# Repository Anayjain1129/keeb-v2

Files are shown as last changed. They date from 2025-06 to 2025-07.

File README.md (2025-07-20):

A badge of a Cerberus and a raccoon laughing together, with the text "HIGHWAY" and "HACK CLUB" beside them.

# Keeb
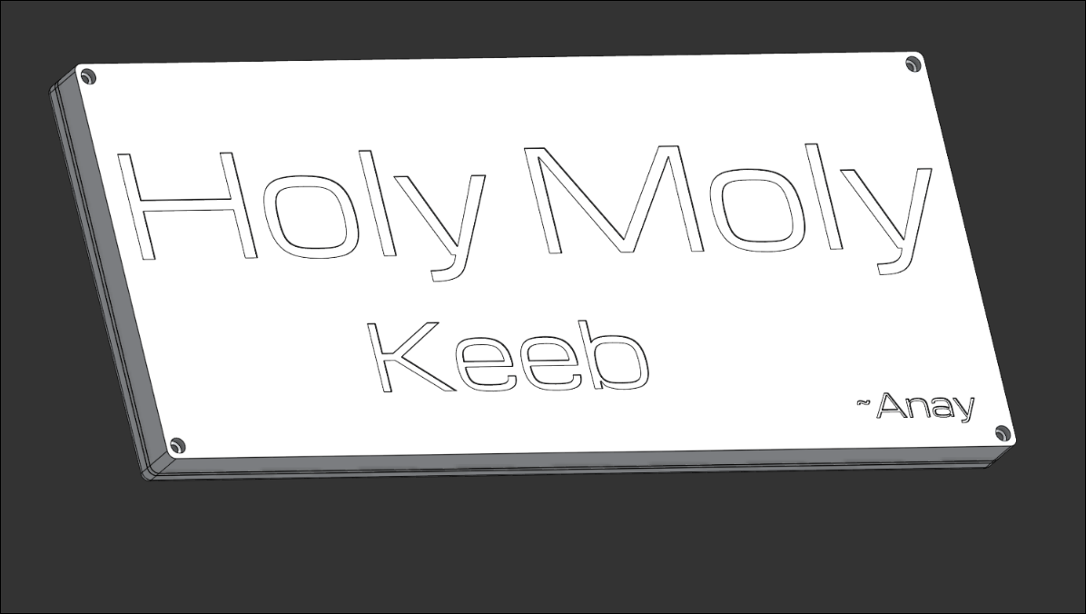
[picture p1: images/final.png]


### Why did I make it?
I made it cause I have a freaking 60% keeb and I really need function keys also It has 2 RE which i can use for like brightness or volume stuff.

### What was the hardest part about this ?
It think everthing was cause it's like I love to learn new things so yea I love to make and learn new thing.

Features:

- 2x EC11 Rotary Encoder - For Volume, Brightness etc
- 74x keys
- Raspberry Pi Pico
- Customised layout
- QMK firmware
- Highway branded PCB and case

### Schematic
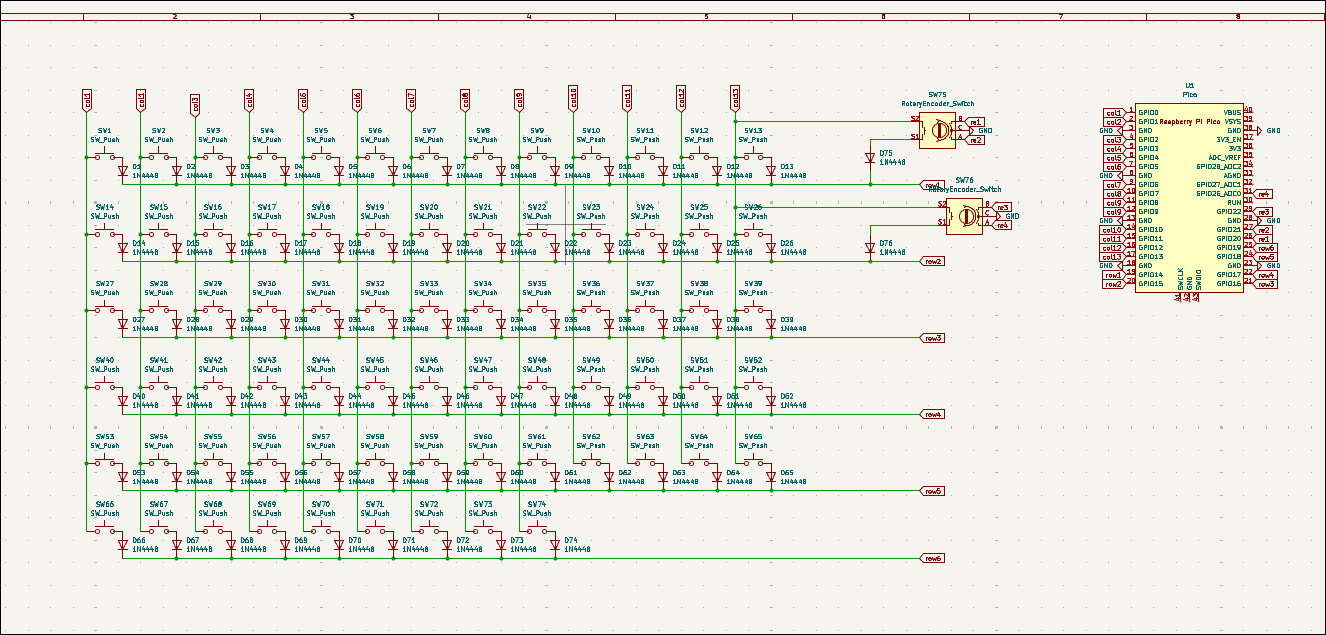
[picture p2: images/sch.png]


### PCB 
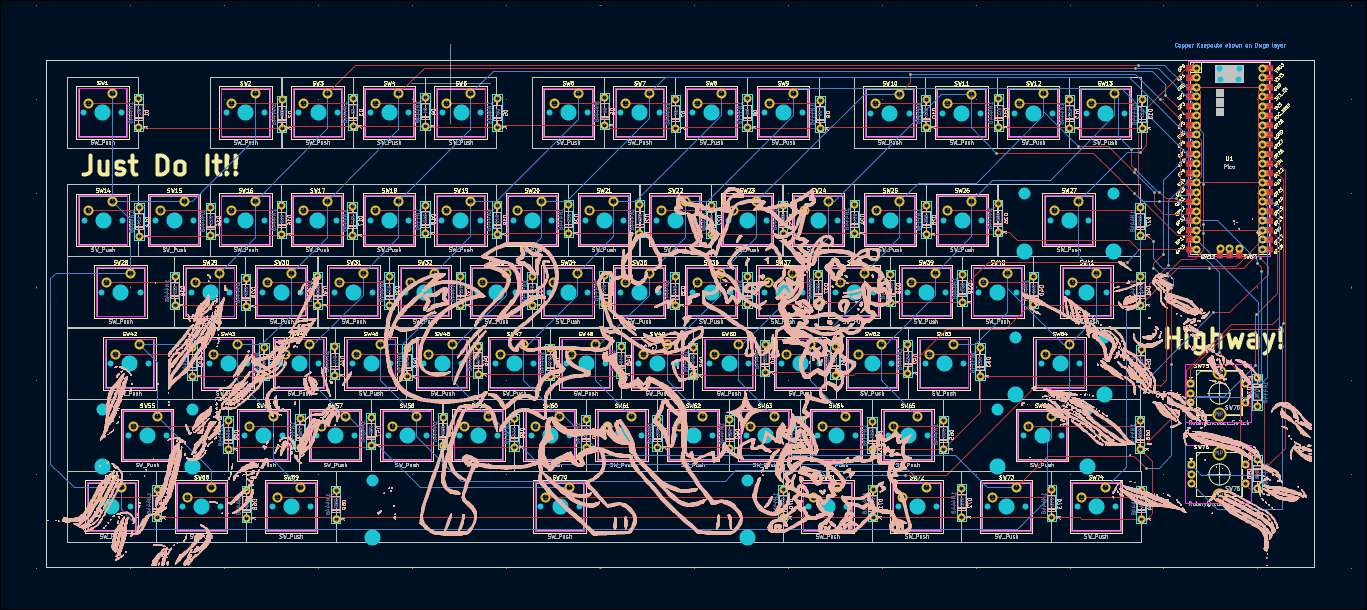
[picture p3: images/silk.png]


### Case
- Bottom
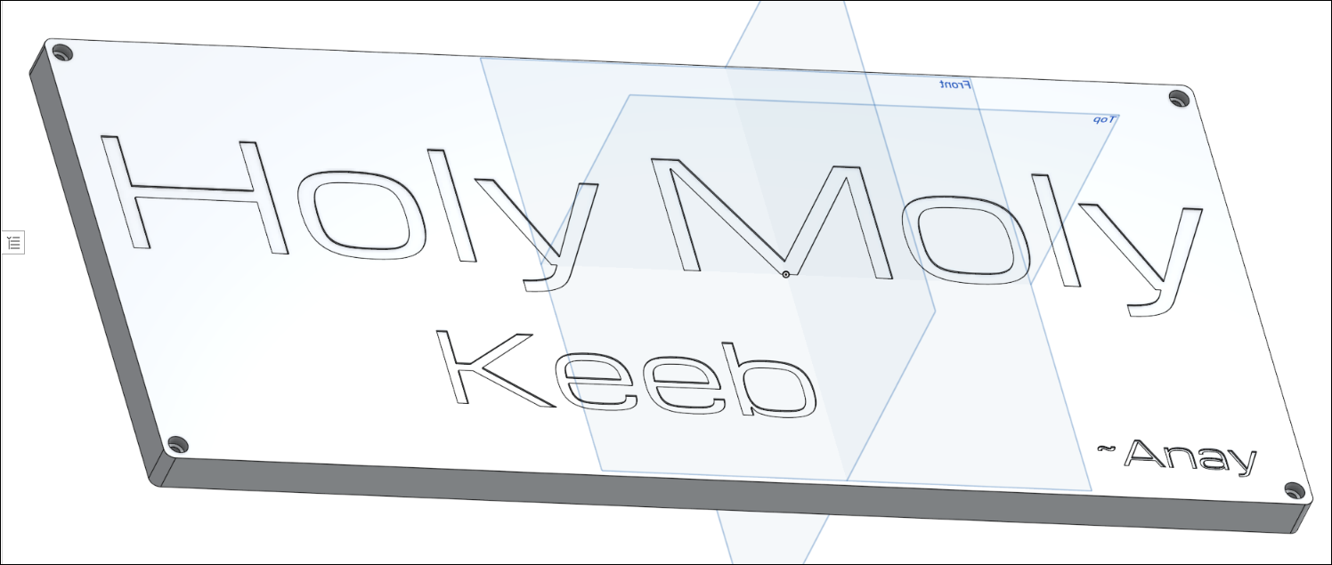
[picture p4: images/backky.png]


- Middle plate
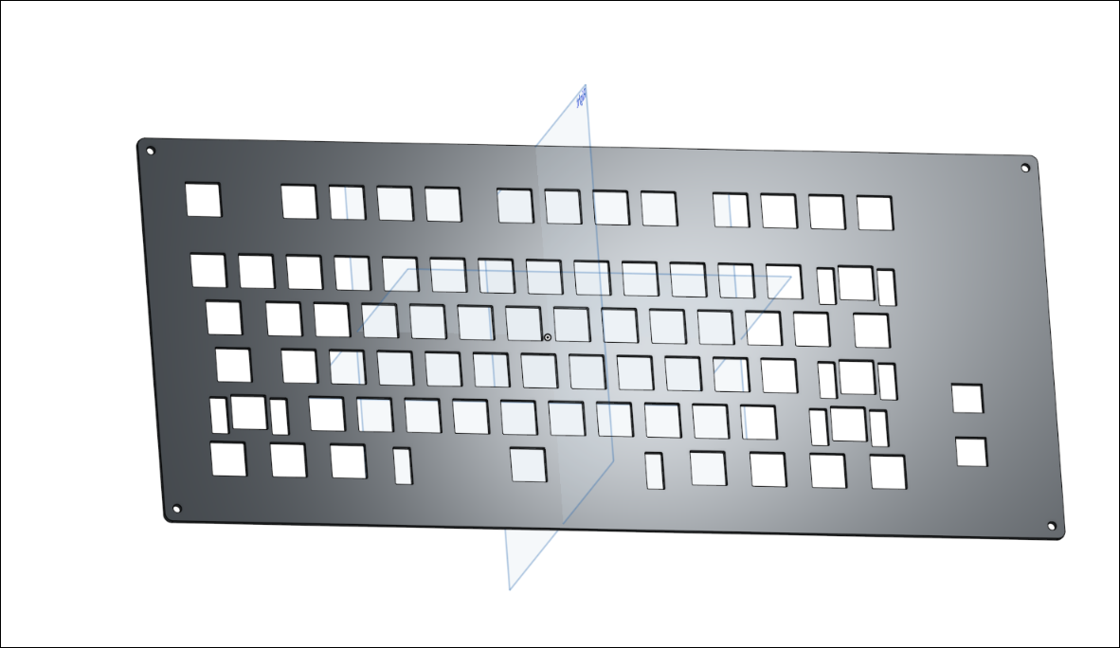
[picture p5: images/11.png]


- Top
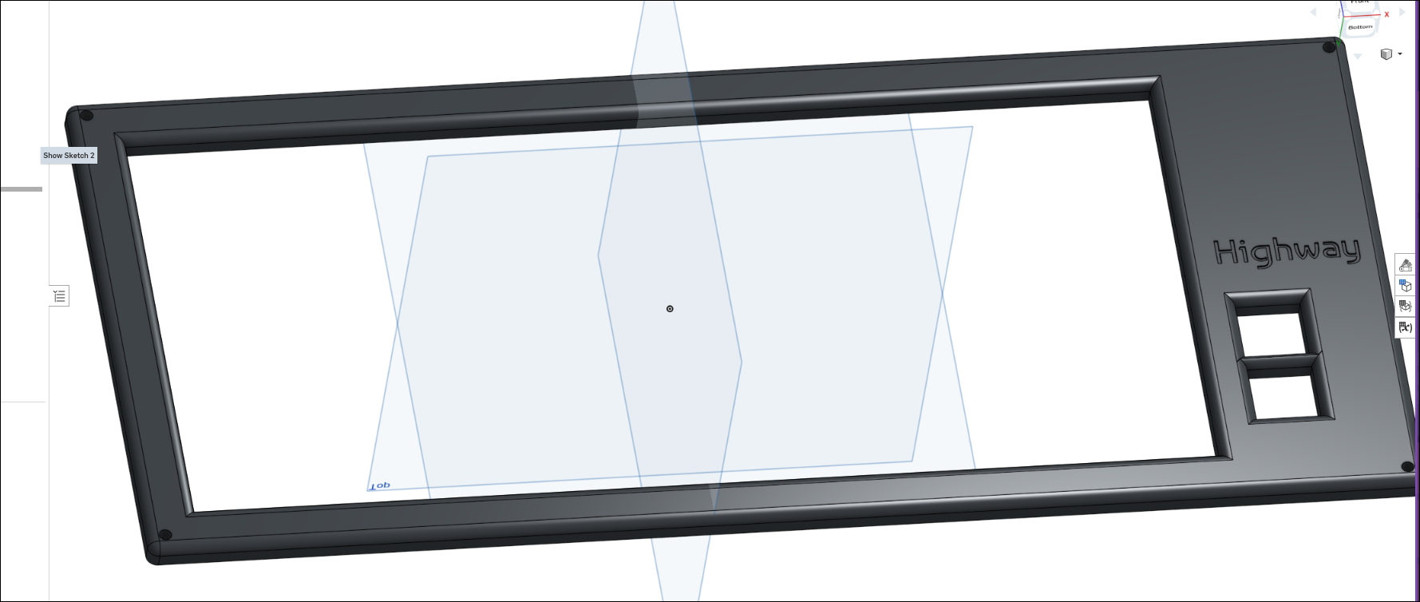
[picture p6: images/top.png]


### 3D view of all parts together 
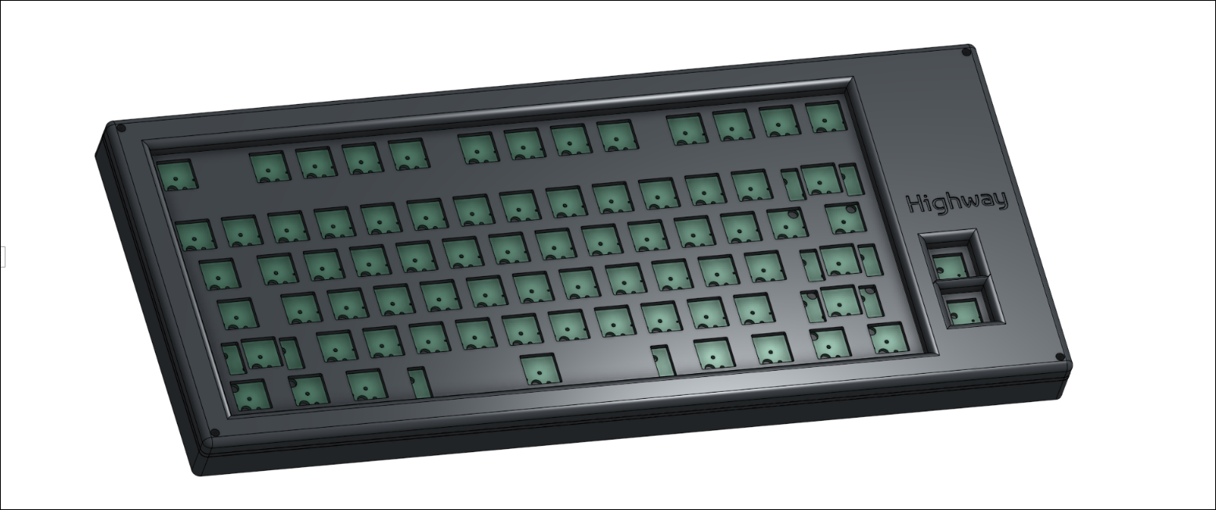
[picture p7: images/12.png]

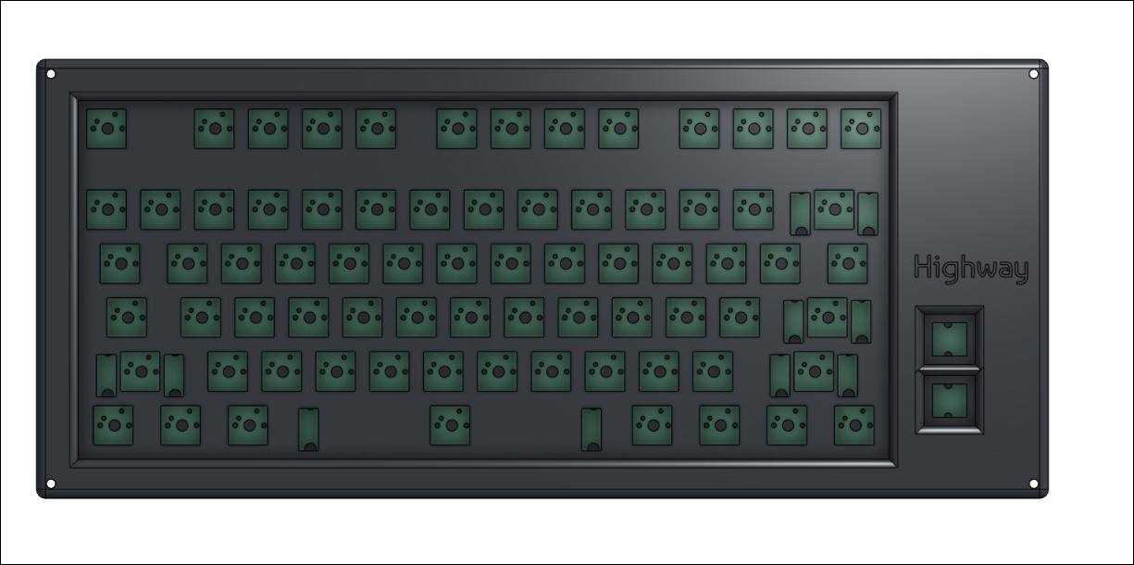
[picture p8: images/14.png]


### Stickers & Handcolor
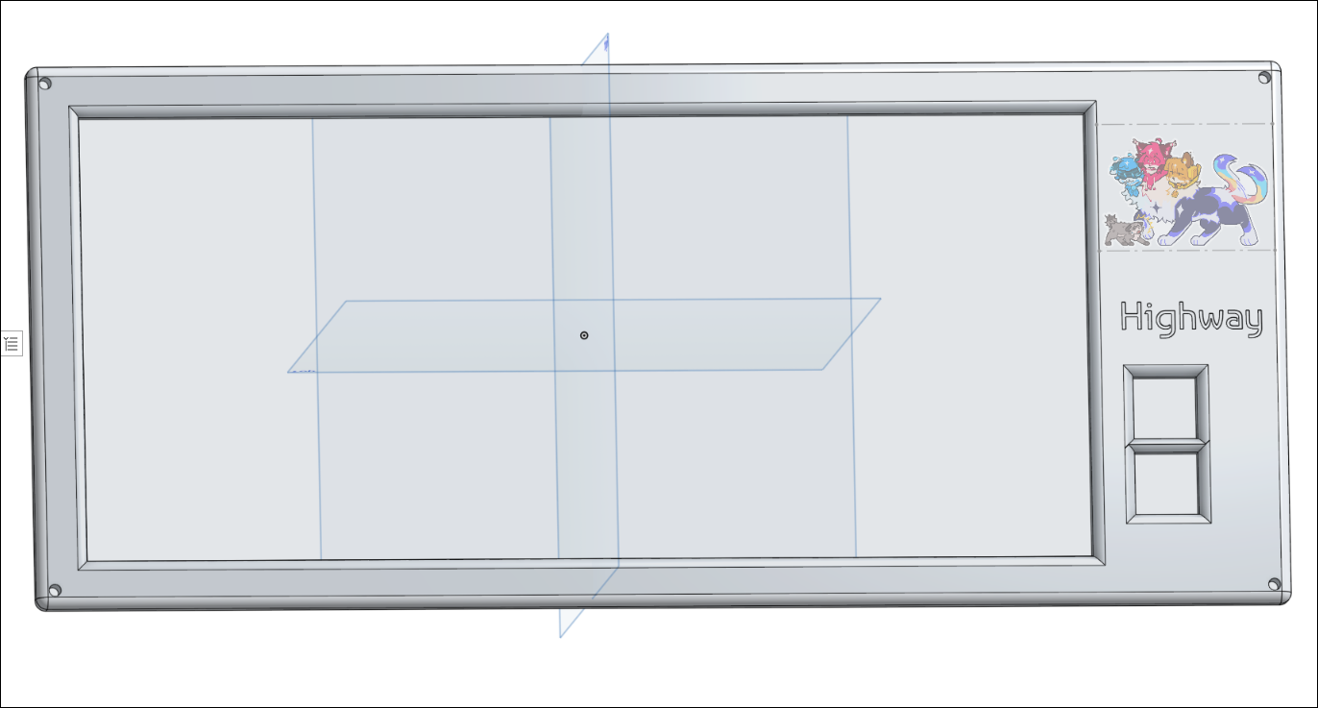
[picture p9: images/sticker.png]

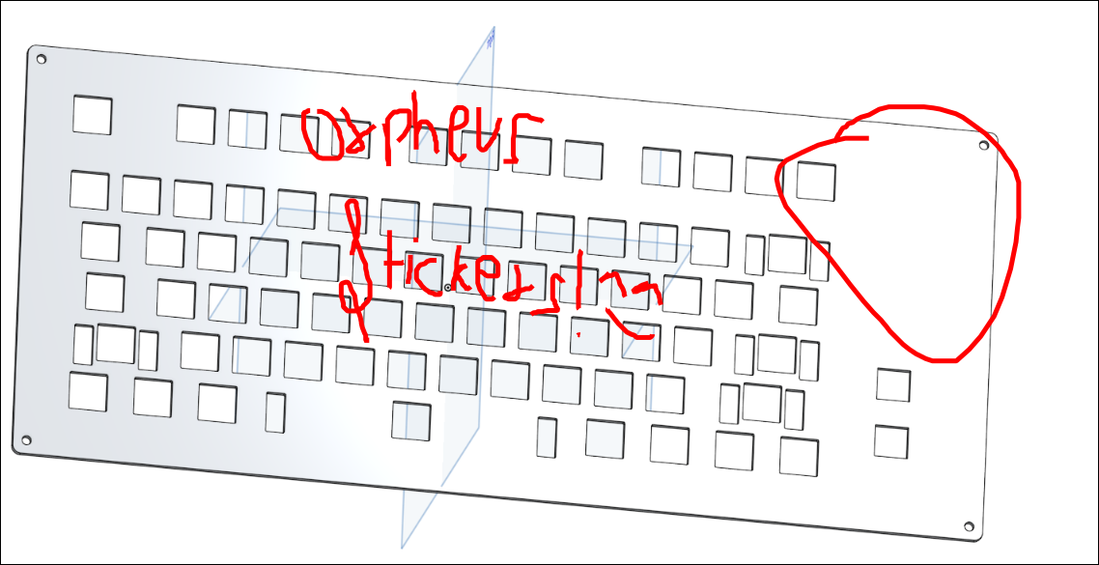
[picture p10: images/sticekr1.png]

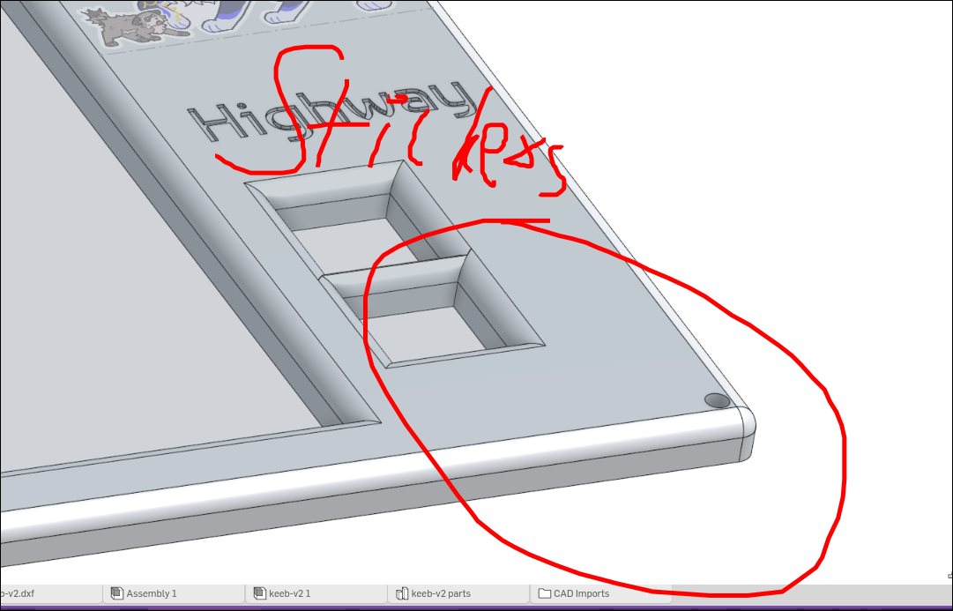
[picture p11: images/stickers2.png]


-Paint
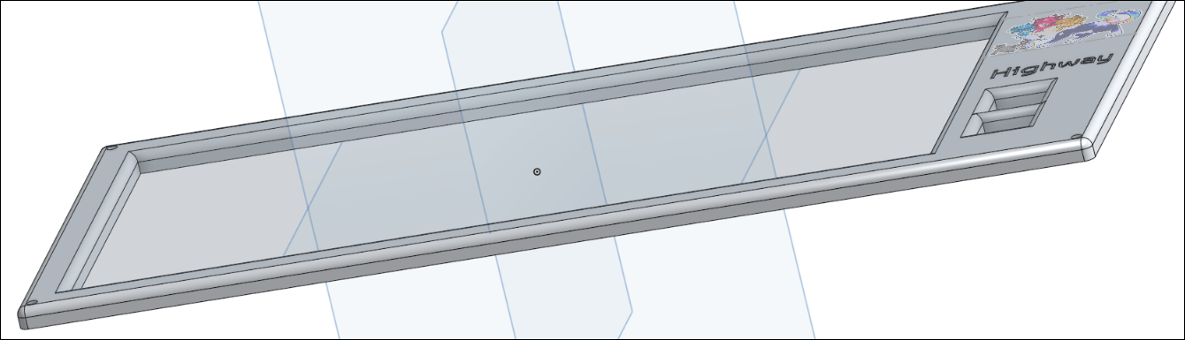
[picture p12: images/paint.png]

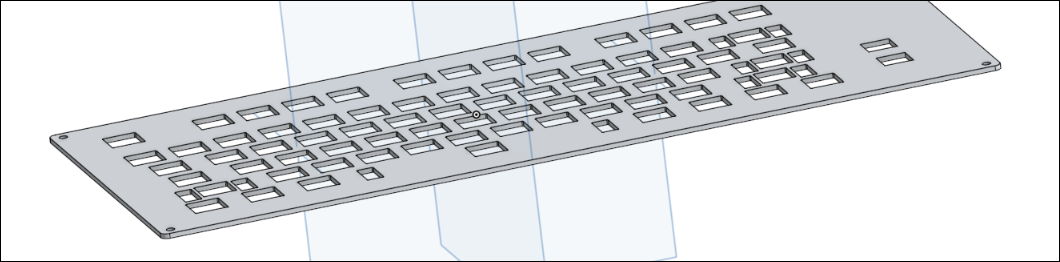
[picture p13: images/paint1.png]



Also at the back part which i have craved some part it is because I'm gonna hand paint it to make it more attractive, I wasn't about to use Blender because I'm cyurrently on Arch and im facing issues. I hope my keeb gets approved now!
I got my sister who is artist so yea sh'e currntly out of station rn but she so many ideas, And like I got so many hackclub stickers so I will use them too.


I have more But I dont have phone rn so i can not take pictures 


I have more But I dont have phone rn so i can not take pictures 

## BOM

| Name | Qty | Final Price - INR (USD) | Link |
| --- | --- | --- | --- |
| Gateron EF Grayish | 80  | 1560 ($18.19) | [here](https://neomacro.in/products/gateron-ef-grayish) |
| Durock Smokey Screw-In Stabilizers V2 (4+1 w/ 6.25u spacebar) | 1 | 1590 ($18.58) | [here](https://stackskb.com/store/durock-smokey-screw-in-stabilizers-v2/) |
| Cherry Profile PBT Keycaps | 1 | 1300 ($15.15) | [here](https://stackskb.com/store/veekos-gradient-keycaps-cherry-profile-135-keys) |
| Diode 1N4148 Through - Hole | 100 | 100 ($1.17) | [here](https://amzn.in/d/j3eLvoh) |
| EC11 Rotary Encoder | 2 | 178 ($2.08) | [here](https://amzn.in/d/hVRxzij) |
| M3 x 20mm Bolt | 15  | 149 ($1.73) | [here](https://amzn.in/d/8GRQWAB) |
| M3 Nuts | 8 | 100 ($1.16) | [here](https://amzn.in/d/7UQtsm8) |
| M3 x 5mm Heatset Insert | 25  | 179 ($2.09) | [here](https://amzn.in/d/ixybuAc) |
| PCB - (Black Color) | 5 | 6683 ($77.78) ||
| Raspberry Pi Pico | 1 | 449 ($5.19) | [here](http://amazon.in/Raspberry-Pi-Headers-Soldered-Micro/dp/B08WPNM7JB/ref=sr_1_2?sr=8-2) |
| Top Case | 1 | Print Legion |
| Bottom Case | 1 | Print Legion |
| Middle Plate | 1 | Print Legion |

## Total Pricing
The total price comes out to be 11,956.35 INR ($139.31) I'm not including the cost of case cause I will get it printed from Print Legion.

The pricing might slightly vary due to flash sales, and dollar market trends.

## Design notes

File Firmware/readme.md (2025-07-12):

# keeb

keeb

*A short description of the keyboard/project*

* Keyboard Maintainer: [anay](https://github.com/anay)
* Hardware Supported: *The PCBs, controllers supported*
* Hardware Availability: *Links to where you can find this hardware*

Make example for this keyboard (after setting up your build environment):

    make keeb:default

Flashing example for this keyboard:

    make keeb:default:flash

See the [build environment setup](https://docs.qmk.fm/#/getting_started_build_tools) and the [make instructions](https://docs.qmk.fm/#/getting_started_make_guide) for more information. Brand new to QMK? Start with our [Complete Newbs Guide](https://docs.qmk.fm/#/newbs).

## Bootloader

Enter the bootloader in 3 ways:

* **Bootmagic reset**: Hold down the key at (0,0) in the matrix (usually the top left key or Escape) and plug in the keyboard
* **Physical reset button**: Briefly press the button on the back of the PCB - some may have pads you must short instead
* **Keycode in layout**: Press the key mapped to `QK_BOOT` if it is available

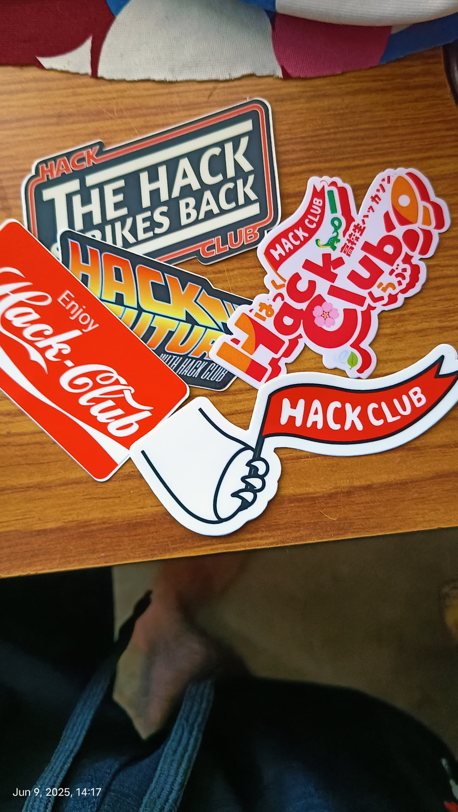
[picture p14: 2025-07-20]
images/col.jpeg

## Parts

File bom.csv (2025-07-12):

Name | Qty | Final Price- INR (USD) | Link
Gateron EF Grayish | 80 | 1560 ($18.19) | https://neomacro.in/products/gateron-ef-grayish
Durock Smokey Screw-In Stabilizers V2 | 1 | 1595 ($18.58) | https://stackskb.com/store/durock-smokey-screw-in-stabilizers-v2/
Cherry Profile PBT Keycaps | 1 | 1300 ($15.15) | https://stackskb.com/store/veekos-gradient-keycaps-cherry-profile-135-keys
Diode 1N4148 Through – Hole | 100 | 100 ($1.17) | https://amzn.in/d/j3eLvoh
EC11 Rotary Encoder | 2 | 178 ($2.08) | https://amzn.in/d/hVRxzij
M3 x 20mm Bolt | 15 | 149 ($1.73) | https://amzn.in/d/8GRQWAB
M3 Nuts | 8 | 100 ($1.16) | https://amzn.in/d/7UQtsm8
M3 x 5mm Heatset Insert | 25 | 179 ($2.09) | https://amzn.in/d/ixybuAc
Raspberry Pi Pico | 1 | 449 ($5.19) | https://www.amazon.in/Raspberry-Pi-Headers-Soldered-Micro/dp/B08WPNM7JB/ref=sr_1_2?sr=8-2
PCB | 5 | 6683 ($77.78)
Top Case | 1 | Print Legion
Bottom Case | 1 | Print Legion
Middle Plate | 1 | Print Legion

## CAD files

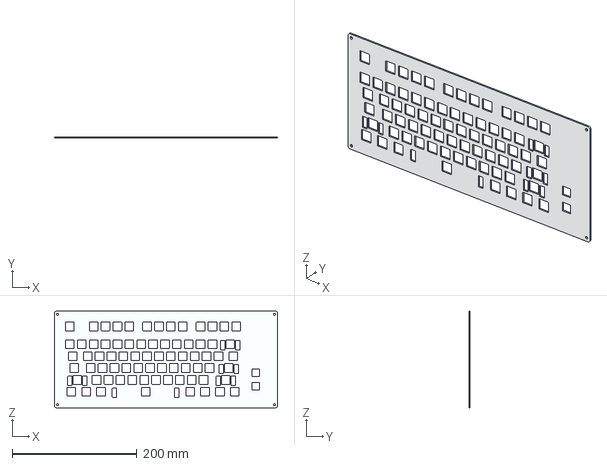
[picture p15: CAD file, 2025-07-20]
CAD/mid.step
357.4 x 2.00 x 154.8 mm

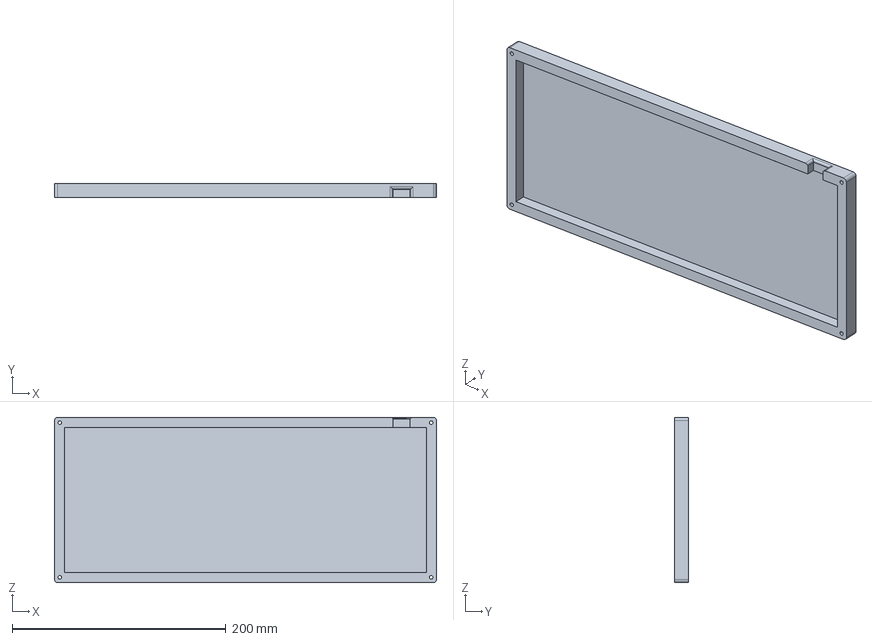
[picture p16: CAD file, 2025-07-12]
Production/CAD/bottom.step
357.4 x 13.0 x 154.8 mm

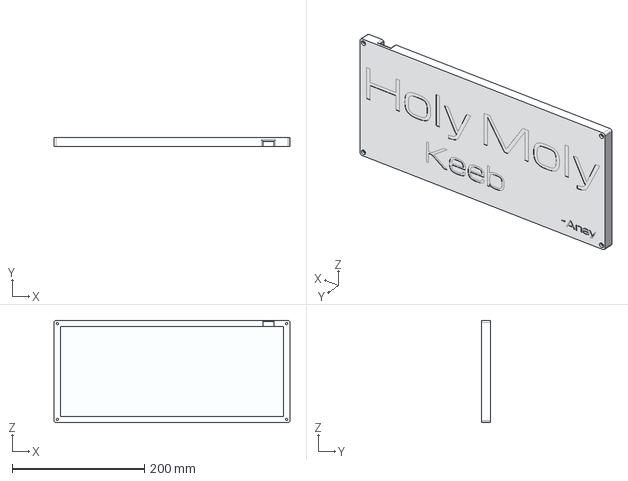
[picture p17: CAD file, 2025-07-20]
CAD/bot.step
357.4 x 13.0 x 154.8 mm

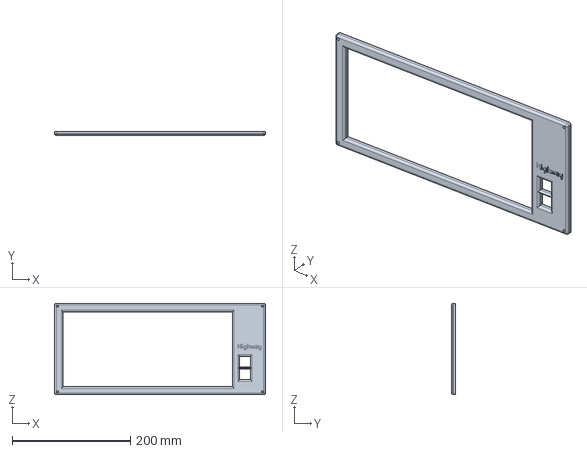
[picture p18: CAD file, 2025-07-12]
Production/CAD/top.step
357.4 x 7.00 x 154.8 mm

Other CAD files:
CAD/top.step
Production/CAD/middle.step

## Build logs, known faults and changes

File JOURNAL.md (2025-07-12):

---
title: "keeb-v2"
author: "@Anayjain1129"
description: "A 74x switches keyboard"
created_at: "2025-06-30"
---

**Total time spent so far: 10hours**

## 30th June: Research & Brainstorming 
>Bro I made the keeb's SCH todayy and I ran out of pins 💀. It was really frustrating for me to Then I search for other options and at the last I came up with Exapnders. 

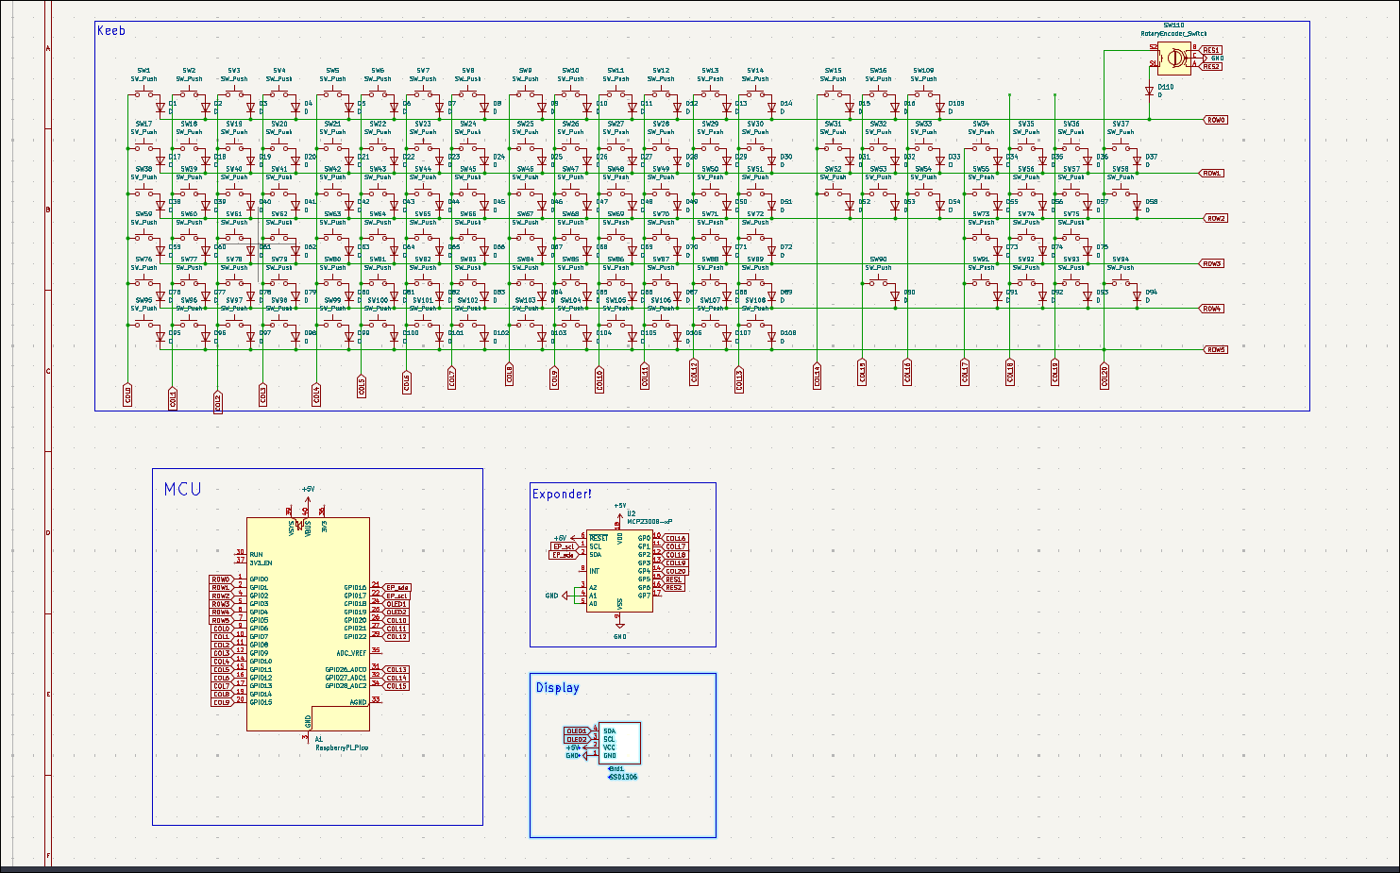
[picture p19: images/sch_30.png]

> Today was a long day it was both really awesome and messy to learn smtg new. I read like the documentation watched yt tuuts and also chadgptttt stuff and aall at the last now i'm done with Sch.

**Time Spent: 3hrs**

## 11th July: PCB & CAD
>Alr So i changes the whole sch cause i dont want a full size bulky keeb so i changed it according to my needs And here is my layout



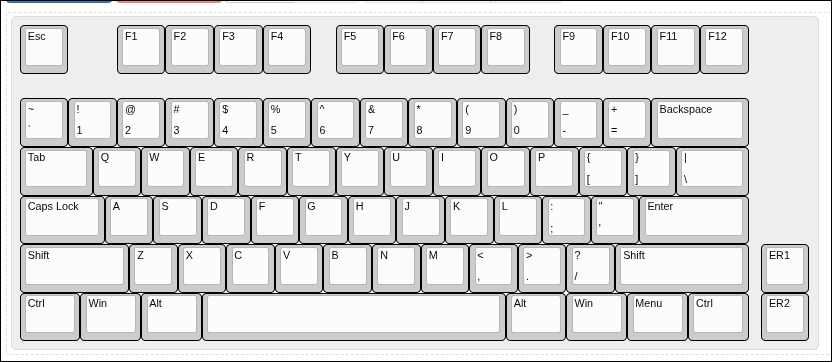
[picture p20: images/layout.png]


>Then i started to work on my PCB. added the keybord svg to place everything in correct place.

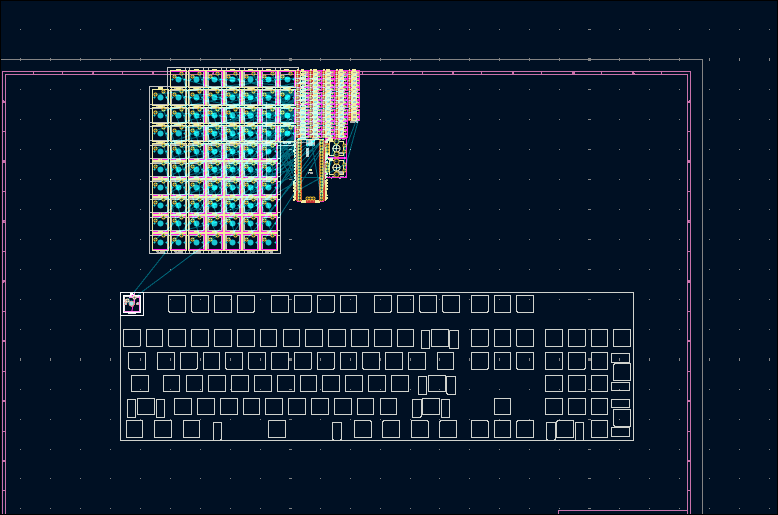
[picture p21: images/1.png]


>Done by first row.



>Alr so i hjave like placed all the switches now I need to place the diodes and my MCU and also the two freaking RE let's gooooooooo!!!!!!!!!!!!!!

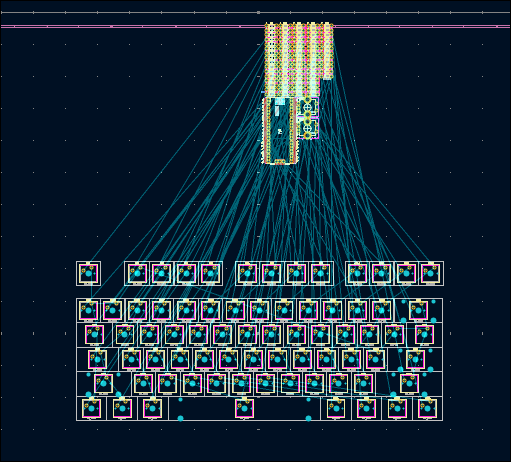
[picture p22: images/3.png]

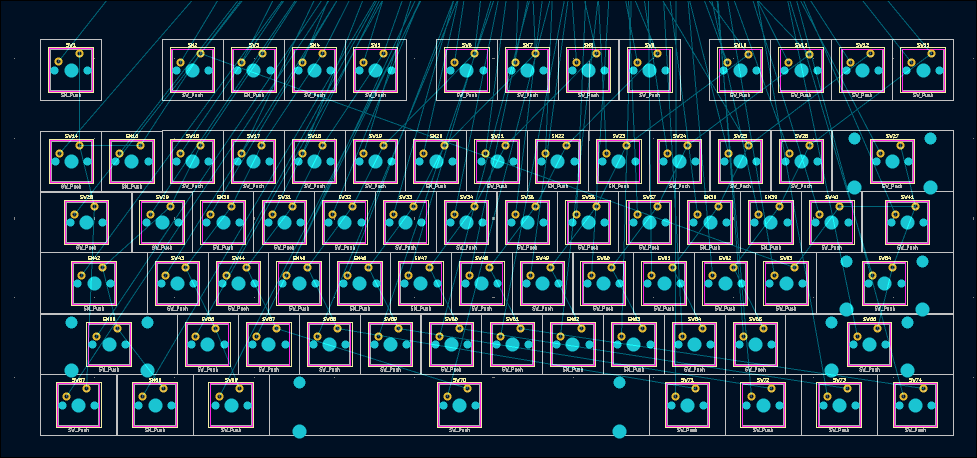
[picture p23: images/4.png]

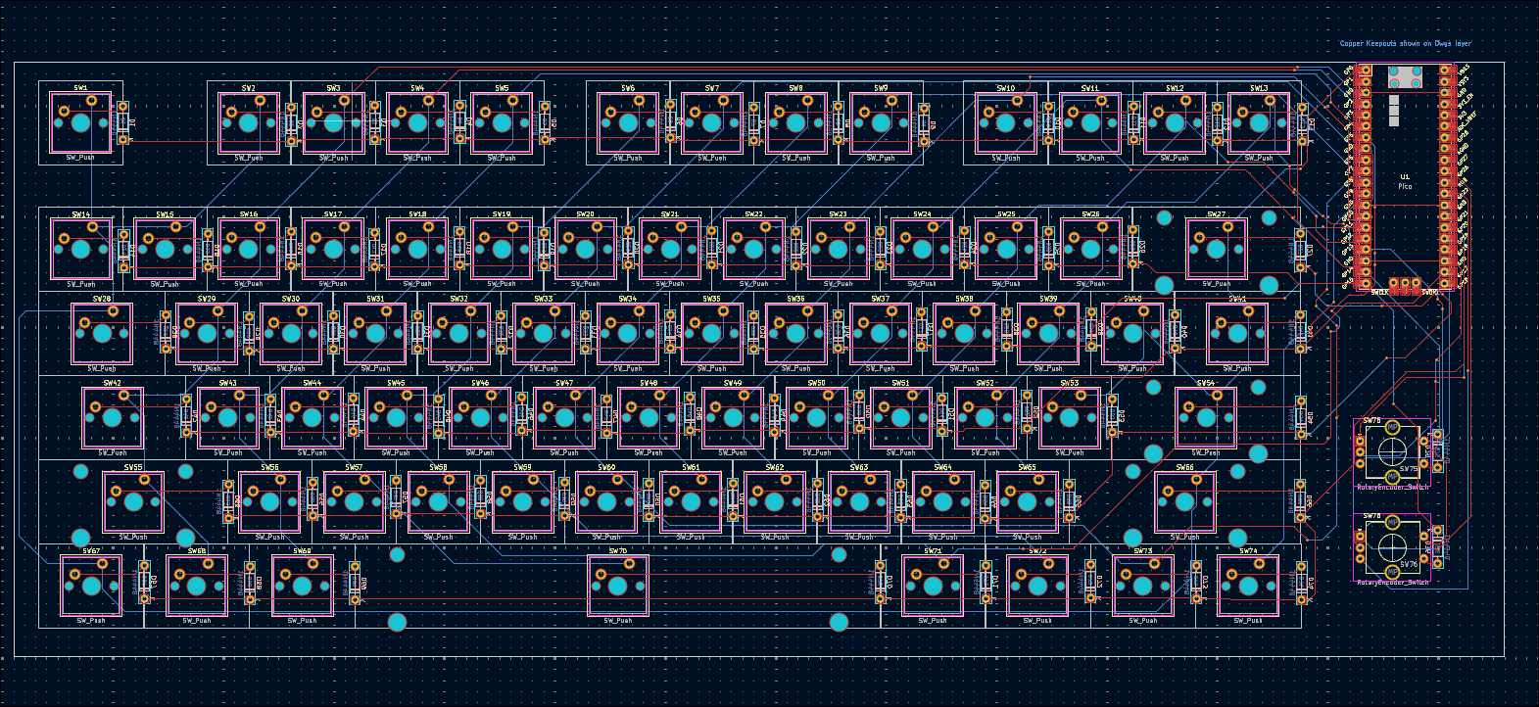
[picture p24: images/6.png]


>Ar I was fucked up doin the wiring part it was really really hard but yea I made through and yea it was kinda fun to do it my father asked what the hel i was doin my exams are goin on so yea :yayy:
>Then i added some Graphics to it and I think I got it then ran the DRC test and it passed so yea im good to go.


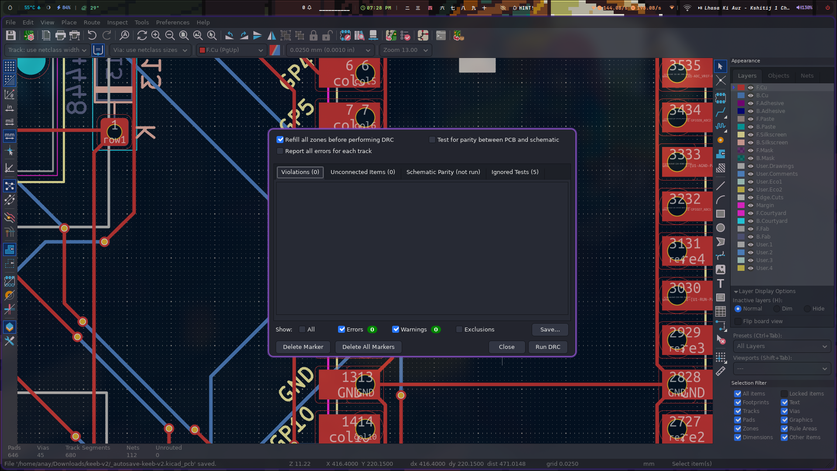
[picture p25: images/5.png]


>Then comes the most exciting part the part that i love CAD yayyyy alr 
>So i made hthe bottom idk how i can explain it here but yea I can attach a ss.

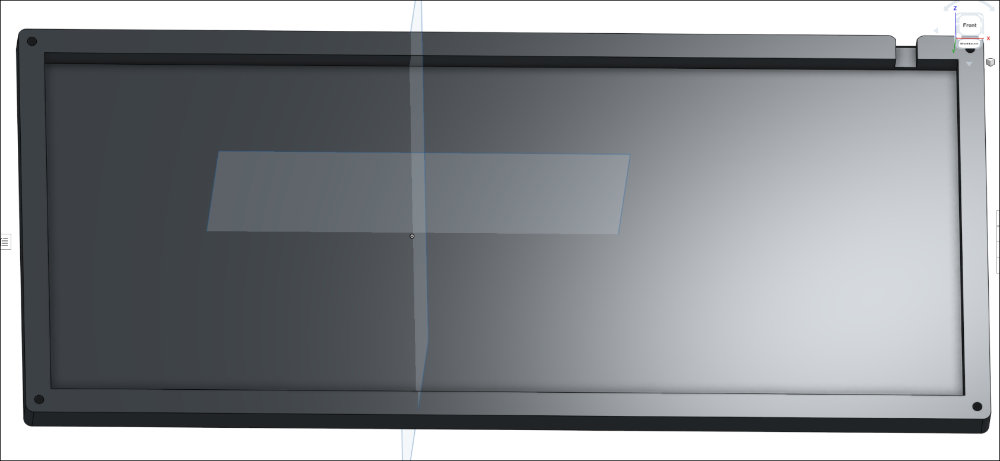
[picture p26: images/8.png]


>Then i used fillet tool to change the curvy things 

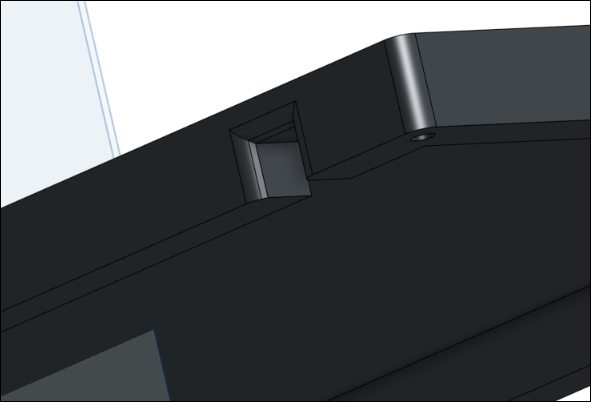
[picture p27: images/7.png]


>her i come to the middle plate part. First i took the measurements and make sure everything fits fine.

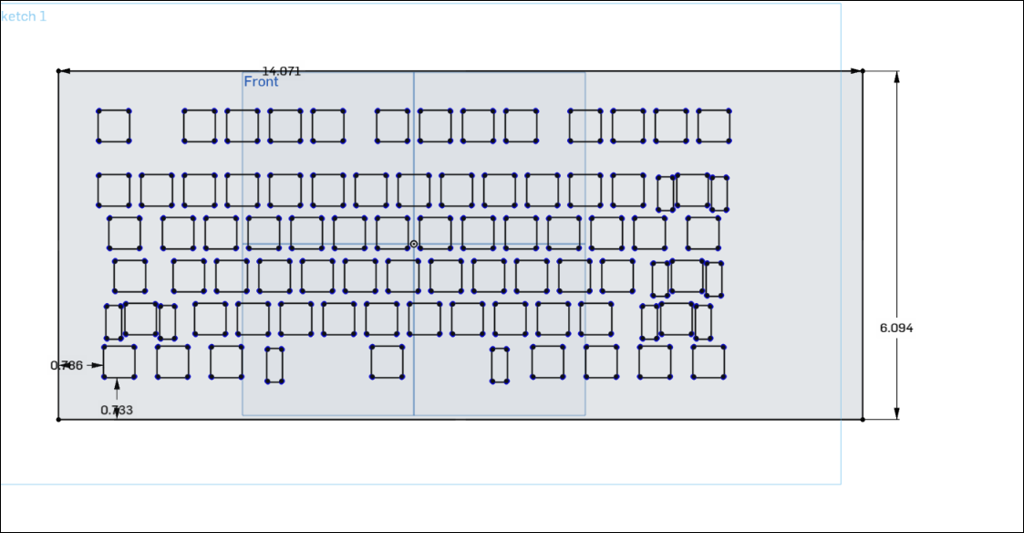
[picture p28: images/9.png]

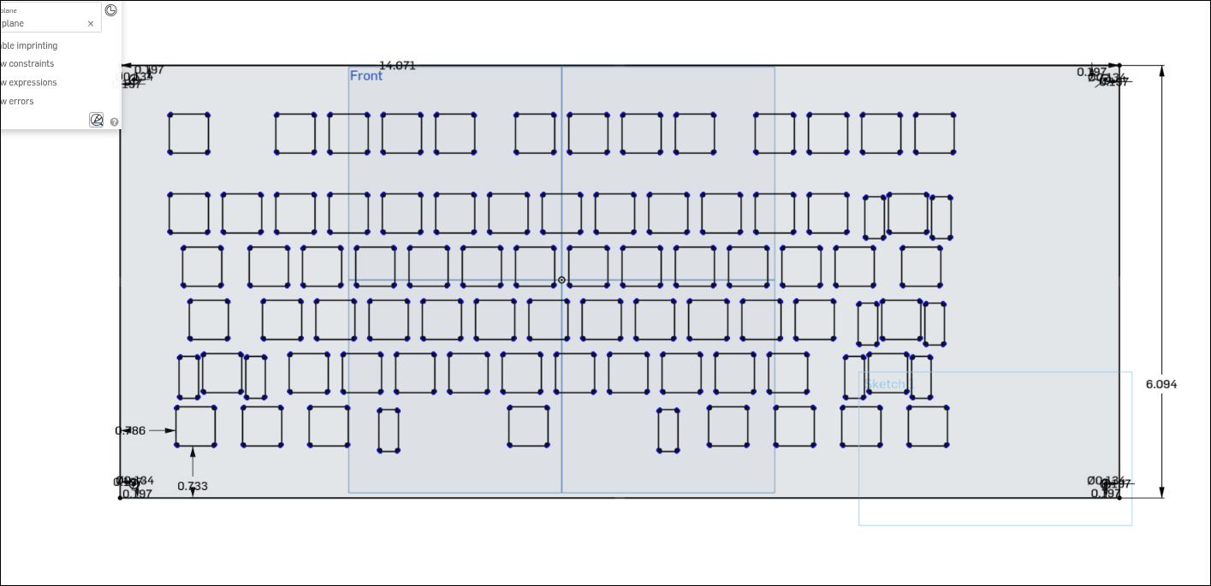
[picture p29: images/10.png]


>Here the result then I again used the fiillet tool.



>Then i came to the top part, againg the measurements the things the fillet and everything the DFX and every thing.



>Then I imported the PCB cad to check if everything fits fine and yea it does 




>Shit man it's time for firmware, alr gotta grind now now im just goin to grind take the help of Chadgpt and claude also Many hackclubbners helped me throughout hte process
>so here it comes got it!! yay

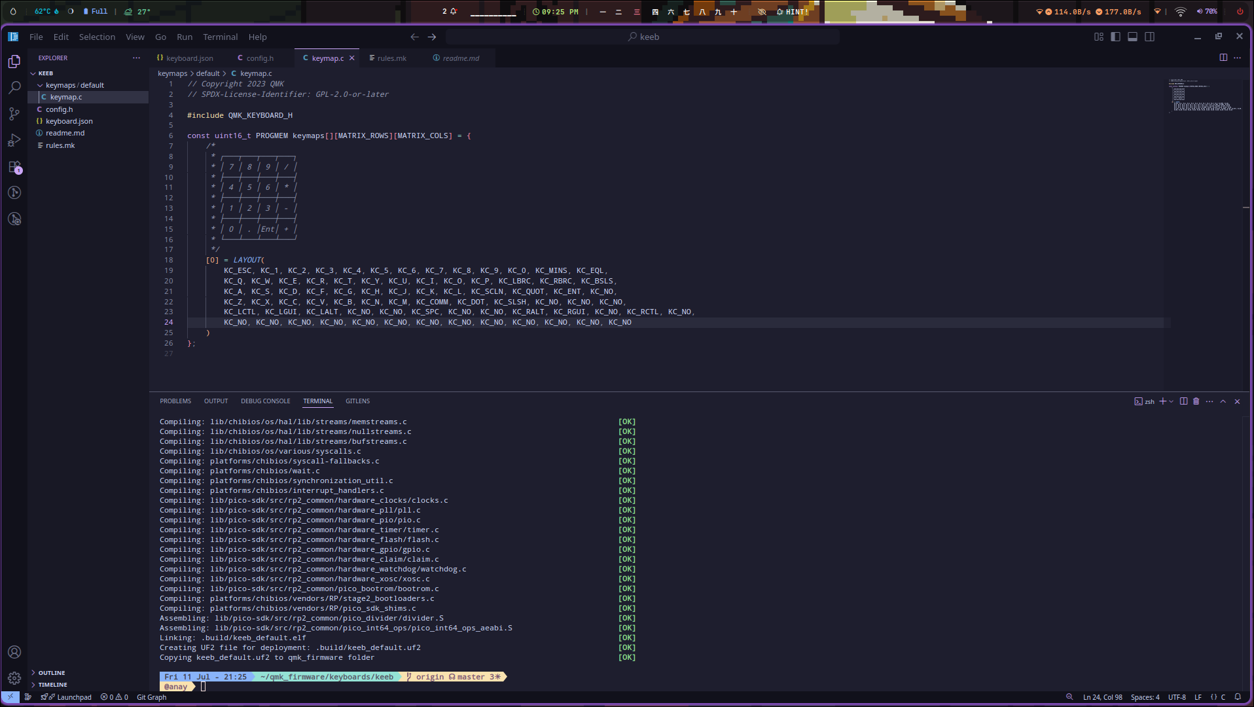
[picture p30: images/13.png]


**Time Spent: 7hrs**

Very very thanks for reading here i
Anay,
signs out

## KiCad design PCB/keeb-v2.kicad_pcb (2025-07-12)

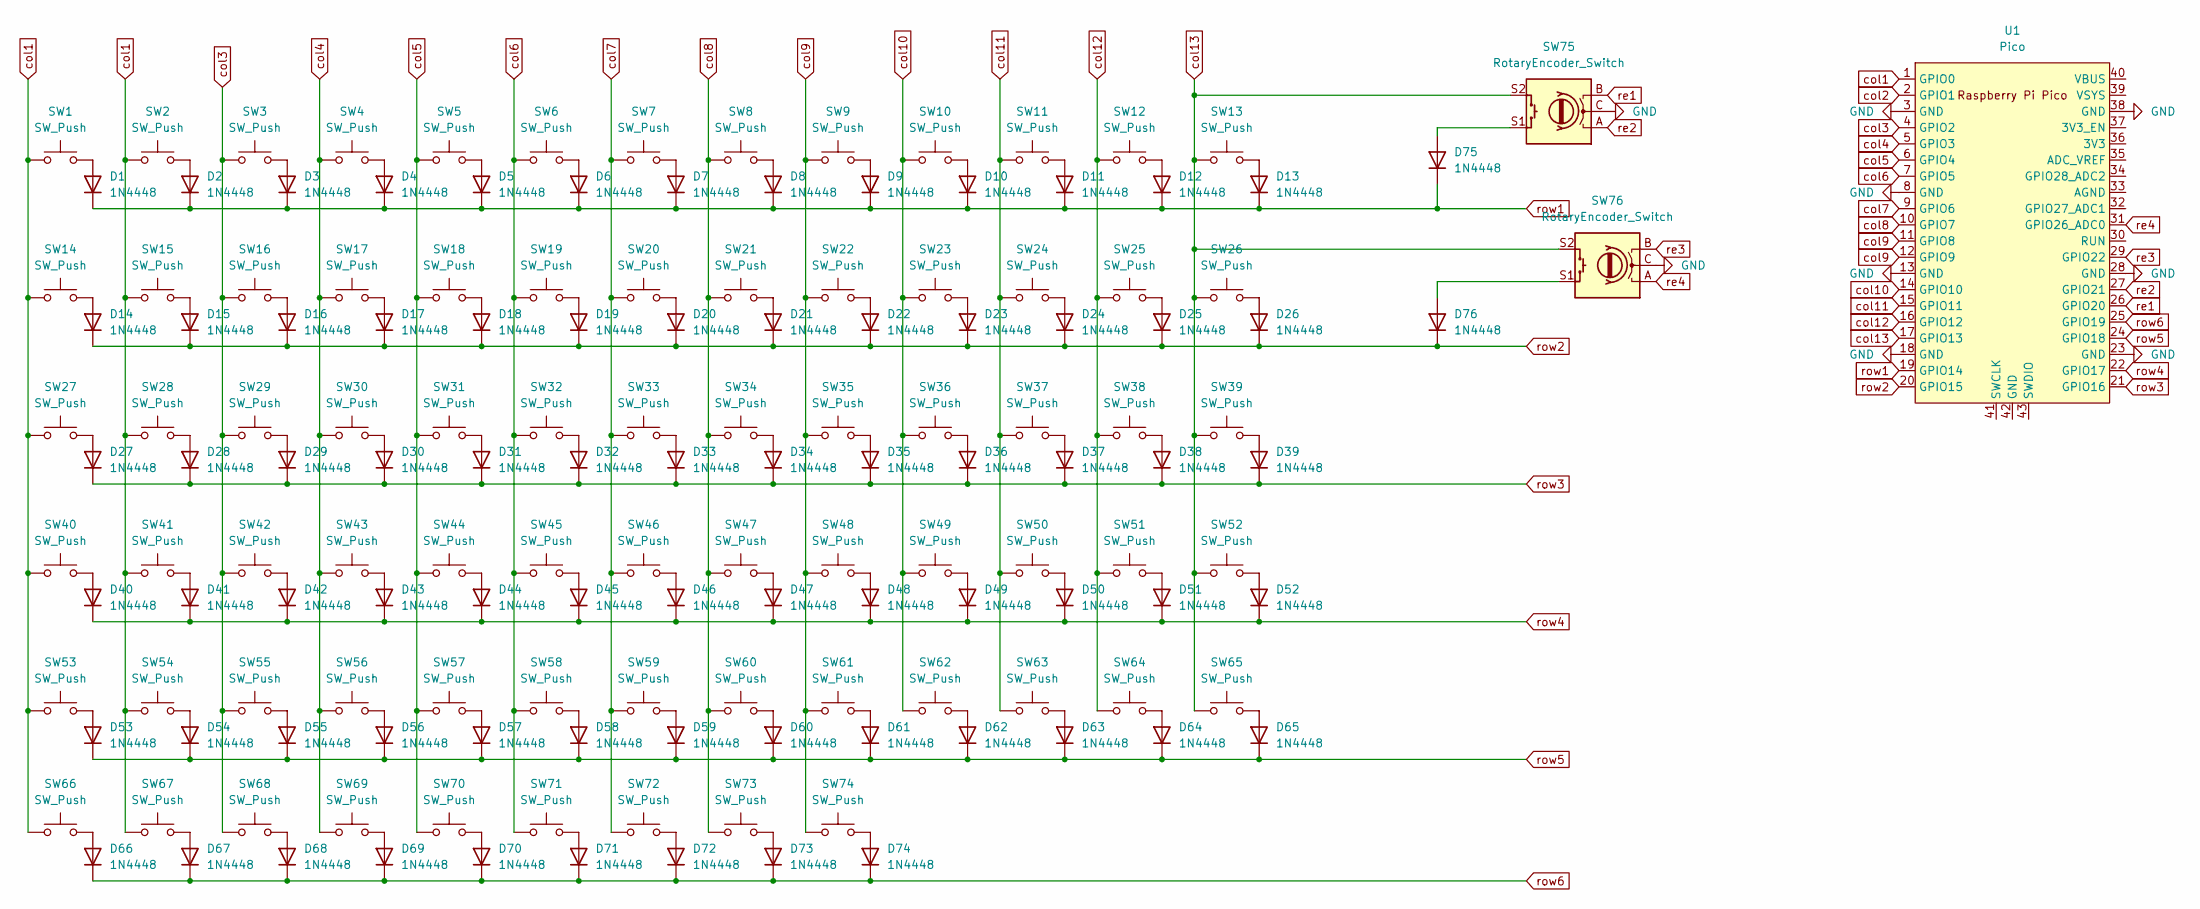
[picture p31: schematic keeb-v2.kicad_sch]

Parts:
D1, D2, D3, D4, D5, D6, D7, D8, D9, D10, D11, D12, D13, D14, D15, D16, D17, D18, D19, D20, D21, D22, D23, D24, D25, D26, D27, D28, D29, D30, D31, D32, D33, D34, D35, D36, D37, D38, D39, D40, D41, D42, D43, D44, D45, D46, D47, D48, D49, D50, D51, D52, D53, D54, D55, D56, D57, D58, D59, D60, D61, D62, D63, D64, D65, D66, D67, D68, D69, D70, D71, D72, D73, D74, D75, D76: 1N4448; D_DO-35_SOD27_P7.62mm_Horizontal
SW1, SW2, SW3, SW4, SW5, SW6, SW7, SW8, SW9, SW10, SW11, SW12, SW13, SW14, SW15, SW16, SW17, SW18, SW19, SW20, SW21, SW22, SW23, SW24, SW25, SW26, SW29, SW30, SW31, SW32, SW33, SW34, SW35, SW36, SW37, SW38, SW39, SW40, SW43, SW44, SW45, SW46, SW47, SW48, SW49, SW50, SW51, SW52, SW53, SW56, SW57, SW58, SW59, SW60, SW61, SW62, SW63, SW64, SW65: SW_Push; SW_Cherry_MX_1.00u_PCB
SW27: SW_Push; SW_Cherry_MX_2.00u_PCB
SW28, SW41: SW_Push; SW_Cherry_MX_1.50u_PCB
SW42: SW_Push; SW_Cherry_MX_1.75u_PCB
SW54, SW55: SW_Push; SW_Cherry_MX_2.25u_PCB
SW66: SW_Push; SW_Cherry_MX_2.75u_PCB
SW67, SW68, SW69, SW71, SW72, SW73, SW74: SW_Push; SW_Cherry_MX_1.25u_PCB
SW70: SW_Push; SW_Cherry_MX_6.25u_PCB
SW75, SW76: RotaryEncoder_Switch; RotaryEncoder_Alps_EC11E-Switch_Vertical_H20mm_CircularMoun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
U1: Pico; RPi_Pico_SMD_TH

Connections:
GND: SW75.C, SW76.C, U1.3 (GND), U1.8 (GND), U1.13 (GND), U1.18 (GND), U1.23 (GND), U1.28 (GND), U1.38 (GND)
unnamed: D1.2 (A), SW1.2
unnamed: D2.2 (A), SW2.2
unnamed: D3.2 (A), SW3.2
unnamed: D4.2 (A), SW4.2
unnamed: D5.2 (A), SW5.2
unnamed: D6.2 (A), SW6.2
unnamed: D7.2 (A), SW7.2
unnamed: D8.2 (A), SW8.2
unnamed: D9.2 (A), SW9.2
unnamed: D10.2 (A), SW10.2
unnamed: D11.2 (A), SW11.2
unnamed: D12.2 (A), SW12.2
unnamed: D13.2 (A), SW13.2
unnamed: D14.2 (A), SW14.2
unnamed: D15.2 (A), SW15.2
unnamed: D16.2 (A), SW16.2
unnamed: D17.2 (A), SW17.2
unnamed: D18.2 (A), SW18.2
unnamed: D19.2 (A), SW19.2
unnamed: D20.2 (A), SW20.2
unnamed: D21.2 (A), SW21.2
unnamed: D22.2 (A), SW22.2
unnamed: D23.2 (A), SW23.2
unnamed: D24.2 (A), SW24.2
unnamed: D25.2 (A), SW25.2
unnamed: D26.2 (A), SW26.2
unnamed: D27.2 (A), SW27.2
unnamed: D28.2 (A), SW28.2
unnamed: D29.2 (A), SW29.2
unnamed: D30.2 (A), SW30.2
unnamed: D31.2 (A), SW31.2
unnamed: D32.2 (A), SW32.2
unnamed: D33.2 (A), SW33.2
unnamed: D34.2 (A), SW34.2
unnamed: D35.2 (A), SW35.2
unnamed: D36.2 (A), SW36.2
unnamed: D37.2 (A), SW37.2
unnamed: D38.2 (A), SW38.2
unnamed: D39.2 (A), SW39.2
unnamed: D40.2 (A), SW40.2
unnamed: D41.2 (A), SW41.2
unnamed: D42.2 (A), SW42.2
unnamed: D43.2 (A), SW43.2
unnamed: D44.2 (A), SW44.2
unnamed: D45.2 (A), SW45.2
unnamed: D46.2 (A), SW46.2
unnamed: D47.2 (A), SW47.2
unnamed: D48.2 (A), SW48.2
unnamed: D49.2 (A), SW49.2
unnamed: D50.2 (A), SW50.2
unnamed: D51.2 (A), SW51.2
unnamed: D52.2 (A), SW52.2
unnamed: D53.2 (A), SW53.2
unnamed: D54.2 (A), SW54.2
unnamed: D55.2 (A), SW55.2
unnamed: D56.2 (A), SW56.2
unnamed: D57.2 (A), SW57.2
unnamed: D58.2 (A), SW58.2
unnamed: D59.2 (A), SW59.2
unnamed: D60.2 (A), SW60.2
unnamed: D61.2 (A), SW61.2
unnamed: D62.2 (A), SW62.2
unnamed: D63.2 (A), SW63.2
unnamed: D64.2 (A), SW64.2
unnamed: D65.2 (A), SW65.2
unnamed: D66.2 (A), SW66.2
unnamed: D67.2 (A), SW67.2
unnamed: D68.2 (A), SW68.2
unnamed: D69.2 (A), SW69.2
unnamed: D70.2 (A), SW70.2
unnamed: D71.2 (A), SW71.2
unnamed: D72.2 (A), SW72.2
unnamed: D73.2 (A), SW73.2
unnamed: D74.2 (A), SW74.2
unnamed: D75.2 (A), SW75.S1
unnamed: D76.2 (A), SW76.S1
col1: SW1.1, SW2.1, SW14.1, SW15.1, SW27.1, SW28.1, SW40.1, SW41.1, SW53.1, SW54.1, SW66.1, SW67.1, U1.1 (GPIO0)
col2: U1.2 (GPIO1)
col3: SW3.1, SW16.1, SW29.1, SW42.1, SW55.1, SW68.1, U1.4 (GPIO2)
col4: SW4.1, SW17.1, SW30.1, SW43.1, SW56.1, SW69.1, U1.5 (GPIO3)
col5: SW5.1, SW18.1, SW31.1, SW44.1, SW57.1, SW70.1, U1.6 (GPIO4)
col6: SW6.1, SW19.1, SW32.1, SW45.1, SW58.1, SW71.1, U1.7 (GPIO5)
col7: SW7.1, SW20.1, SW33.1, SW46.1, SW59.1, SW72.1, U1.9 (GPIO6)
col8: SW8.1, SW21.1, SW34.1, SW47.1, SW60.1, SW73.1, U1.10 (GPIO7)
col9: SW9.1, SW22.1, SW35.1, SW48.1, SW61.1, SW74.1, U1.11 (GPIO8), U1.12 (GPIO9)
col10: SW10.1, SW23.1, SW36.1, SW49.1, SW62.1, U1.14 (GPIO10)
col11: SW11.1, SW24.1, SW37.1, SW50.1, SW63.1, U1.15 (GPIO11)
col12: SW12.1, SW25.1, SW38.1, SW51.1, SW64.1, U1.16 (GPIO12)
col13: SW13.1, SW26.1, SW39.1, SW52.1, SW65.1, SW75.S2, SW76.S2, U1.17 (GPIO13)
re1: SW75.B, U1.26 (GPIO20)
re2: SW75.A, U1.27 (GPIO21)
re3: SW76.B, U1.29 (GPIO22)
re4: SW76.A, U1.31 (GPIO26_ADC0)
row1: D1.1 (K), D2.1 (K), D3.1 (K), D4.1 (K), D5.1 (K), D6.1 (K), D7.1 (K), D8.1 (K), D9.1 (K), D10.1 (K), D11.1 (K), D12.1 (K), D13.1 (K), D75.1 (K), U1.19 (GPIO14)
row2: D14.1 (K), D15.1 (K), D16.1 (K), D17.1 (K), D18.1 (K), D19.1 (K), D20.1 (K), D21.1 (K), D22.1 (K), D23.1 (K), D24.1 (K), D25.1 (K), D26.1 (K), D76.1 (K), U1.20 (GPIO15)
row3: D27.1 (K), D28.1 (K), D29.1 (K), D30.1 (K), D31.1 (K), D32.1 (K), D33.1 (K), D34.1 (K), D35.1 (K), D36.1 (K), D37.1 (K), D38.1 (K), D39.1 (K), U1.21 (GPIO16)
row4: D40.1 (K), D41.1 (K), D42.1 (K), D43.1 (K), D44.1 (K), D45.1 (K), D46.1 (K), D47.1 (K), D48.1 (K), D49.1 (K), D50.1 (K), D51.1 (K), D52.1 (K), U1.22 (GPIO17)
row5: D53.1 (K), D54.1 (K), D55.1 (K), D56.1 (K), D57.1 (K), D58.1 (K), D59.1 (K), D60.1 (K), D61.1 (K), D62.1 (K), D63.1 (K), D64.1 (K), D65.1 (K), U1.24 (GPIO18)
row6: D66.1 (K), D67.1 (K), D68.1 (K), D69.1 (K), D70.1 (K), D71.1 (K), D72.1 (K), D73.1 (K), D74.1 (K), U1.25 (GPIO19)

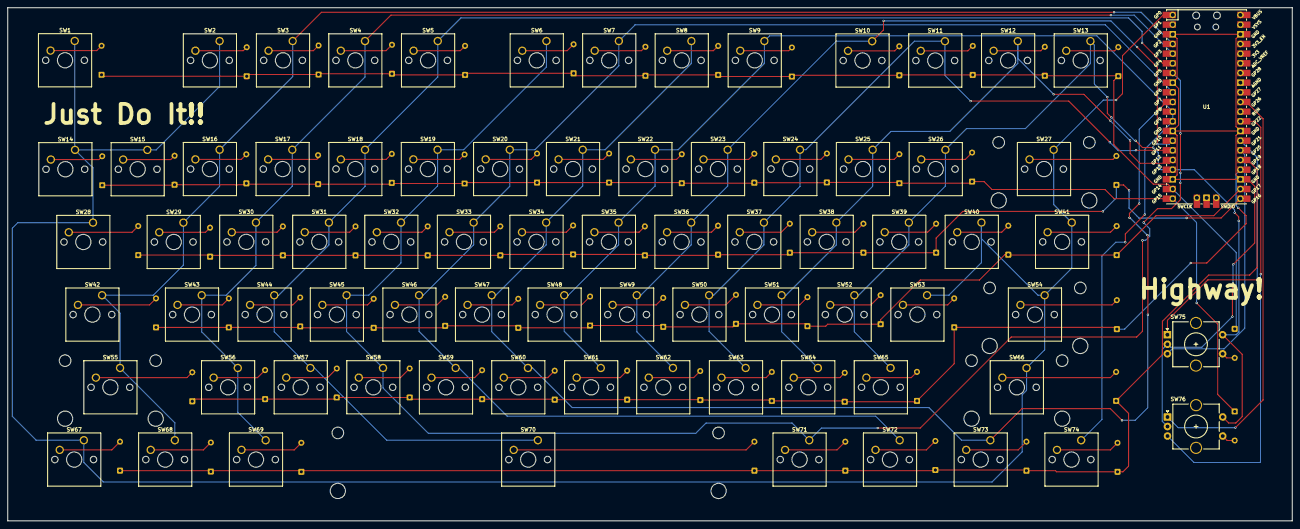
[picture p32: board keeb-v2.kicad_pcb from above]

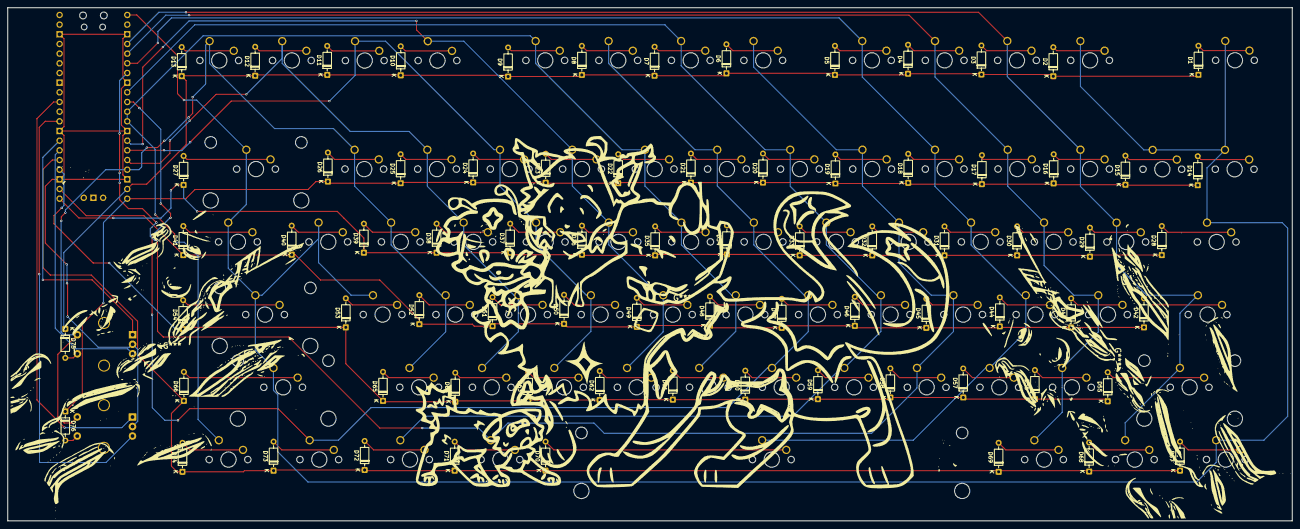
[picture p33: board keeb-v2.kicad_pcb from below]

Board: 2 copper layers, 337.4 x 134.8 mm, 153 parts (76 on the bottom side), 99 nets.
